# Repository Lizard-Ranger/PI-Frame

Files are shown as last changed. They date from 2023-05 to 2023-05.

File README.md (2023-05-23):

# PI Frame 
Google Drive folder powered Raspberry Digital Photo Frame

I built this as a gift for my Mother on her birthday.

The requirements for this build:
 - Raspberry pi 3 B+
 - 32 Gb Micro SD card
 - Wave 10.1" Capacitive Touch LCD D 1024X600 
 - HDMI Male - Ribbon Connector (Straight) 
 - HDMI Ribbon Cable 10cm
 - DC Jack Female 2155 Pigtail Cable - 500mm
 - DC Jack Male 2155 Pigtail Cable
 - HDMI LCD Controller - 40 Pin 
 - DC-DC Buck Voltage Regulator, Vin 6-18V Vout 5V 4.5A 
 - AC Adapter 12V 5A
 - Micro USB Connector + Pigtail 4 Pin Cable
 - Super glue
 - Printed Parts (1 x Picture Frame, 2 x Leg)
	
Build Steps
- Instert the DC Jack Female
- **_NB NB Please Double check Polarity_**
- Solder the DC Jack Female and DC Jack male ends to the DC Buck Voltage Regulator's **Input (VIN)**
- Solder Micro USB cable to the 5v output (**NB Red is +, Black is - (VOUT)** )
- Connect all cables and ribbon cables.
	
If all is connected correctly the display connected to the Raspberry PI will work once the SD card is in and booted.
	
Installation process

** MB ** Keyboard and Mouse will be needed.

- Image SD card with **Raspberry PI Imager**
- 	Choose **Debian Bulleseye with the Raspberry Pi Desktop**
-	Boot Raspberry PI (Wait for it to complete the process)
- 	It will
- 	Resize the storage
- 	Prompt for
- 	Location and Language
- 	Username and Password
-	Wireless connectivity
- 	Upgrades
	
Once complete and booted into the Desktop
- open raspi-config one of two ways
  -	Terminal - sudo raspi-config
  -	Desktop  - menu -> Preferances -> Raspberry PI Configuration
		
Things to change
- **System**
  - Hostname
  - Network at Boot = Yes
- **Display**
  - Screan Blanking = Yes
  - Interfaces
  - SSH = Yes
  - VNC = Yes
  - Basic config is now complete
	
- Now download the install.sh script to the Raspberry Home Directory (/home/pi).
  - Correct Permissions 
  - sudo chmod +x install.sh
	
Things to edit in the install.sh file is the Root Password.
	
-	nano install.sh
	- (username="root" **new_password="password"** Please replace password to your desired password.)

Now you can run it.
- ./install.sh

During the install prossess.
- Update and Upgrade will run.
- Packages **ntp**, **feh**, **rsync** and **xscreensaver** will installed.
- RustDesk will be downloaded and installed.
- Bluetooth and screensaver will be disabled.
- Repos and keys added for **ocamlfuse** (Google Drive Connector)
- MyGDrive will be created and mapped.
- Screen Saver will be disabled.
- All scripts will be placed the '/home/pi/frame' Directory.
		
Three Scripts will be created.
- feh.sh
  -	Runs the slide show on the screen.
- gdconnect.sh
  -	Connects the mapped drive.
- GDrive_sync.sh
  -	Removed Pictures from the Pictures folder.
  - Empties the trash folder.
  - Copies pictures from the MyGDrive folder to Pictures folder.
  - Then reboots the Raspberry PI.
		
File permissions will be corrected.
Crobtab will be updated to automate the prossess ( Will run every Friday @ Midnight).

- The last part once the script is complete from the desktop.
- Run **google-drive-ocamlfuse /home/pi/MyGDrive** from the terminal screen.
- This will supply a URL for the Google Authentication, copy it and run it from the Desktop Web browser.
- This will prompt you to enter you Google username and Password, and ask you to allow **gfuse**
- Once you have allowed it close the web browser, in the terminal screen you will see tocken created.
- Run **./GDrive_sync.sh** to Sync Pictures
- Reboot the Raspberry PI.

Thank you for using this script.

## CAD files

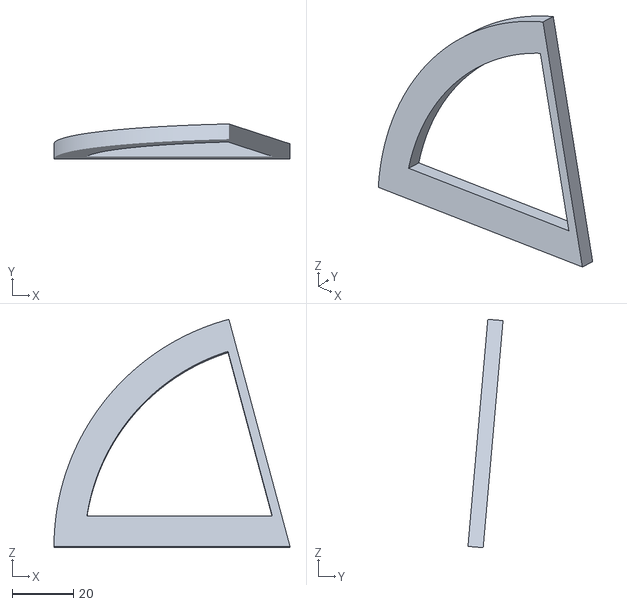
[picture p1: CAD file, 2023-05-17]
3D Print Files/Leg.stl
77.0 x 11.5 x 74.6

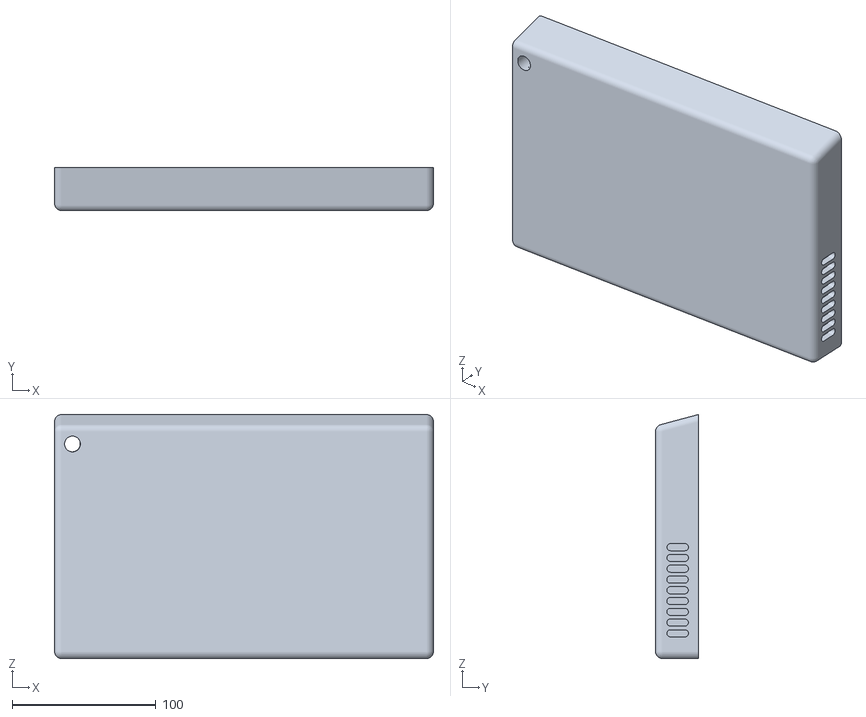
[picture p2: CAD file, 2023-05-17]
3D Print Files/Picture Frame.stl
264.0 x 30.0 x 170.0

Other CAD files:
3D Print Files/Leg.f3d
3D Print Files/Leg.skp
3D Print Files/Picture Frame.f3d
3D Print Files/Picture Frame.skp

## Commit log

2023-05-17 Added 3D files
    Added 3D files
    Export for Fusion 360
    Export for Sketchup
    Export For SLT
    [Leg.f3d, Leg.skp, Leg.stl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]
2023-05-23 Addition of new features
    New features - TESTING
    - Forced Update on 30min schedual via cronjob.(picture frame to look for a "true" statment in the mpf/commands folder before attempting to re-cync.
